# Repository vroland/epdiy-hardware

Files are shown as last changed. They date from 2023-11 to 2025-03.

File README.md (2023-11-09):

# EPDiy Hardware 

Design files for [EPDiy](https://github.com/vroland/epdiy) controllers, controller variants, display adaptors, and other related hardware.  
See [vroland.github.io/epdiy-hardware/](https://vroland.github.io/epdiy-hardware/) for available hardware.

## What is EPDiy?

Please refer to the [main project repository](https://github.com/vroland/epdiy) for more information.

## Cloning

Make sure to clone recursively, to get hardware library submodules:
```
git clone git@github.com:vroland/epdiy-hardware.git --recursive
# or with http
git clone https://github.com/vroland/epdiy-hardware.git --recursive
```

## Contributing Hardware

Contributions in the form of adapter boards, utilities or epdiy variants are always welcome!
Please submit a PR and make sure your KiCAD project is in the right format, so our automation can build 
the manufacturing files and overview page:

* For every board, the KiCAD project should be given a unique name, and have the same name as the containing folder. 
  Example: `epdiy-v7/epdiy-v7.{kicad_pro,kicad_pcb,kicad_sch}`. 
  An existing KiCAD project can be renamed by selecting `File -> Save As` in the main KiCAD window and saving it to a folder with the new name.
* Unless you *explicitly* specify otherwise, your contribution will be licensed under the Creative Commons Attribution-ShareAlike 4.0 International License.
  Feel free to mention in the README in your project folder how you want to be attributed.
  Please indicate in the PR if you intend to use a different license.
* Each board needs a README.md in it's project folder, which will also appear as description in the presentation page.
  Refer to `epdiy-v7/README.md` for an example.
* If it's a helper or an adapter board, place it in the appropriate `helpers` or `adapters` folder.
* Delete the manufacturing files and keep only the sources.
  Since we generate those automatically, having potentially outdated ones in the repo will be confusing. 
* Add your board to the `BOARDS` list in the root `Makefile`.
  This enables the continuous integration to build the manufacturing files for your board.

## Available Hardware

The full list of available hardware is available at [vroland.github.io/epdiy-hardware/](https://vroland.github.io/epdiy-hardware/).
For each board, we provide:

- Gerber files
- Bill of Materials (BoM)
- Pick & Place Positioning file
- PDF Schematic
- 3D model of the board for use in CAD

## Licensing

Unless otherwise specified, the hardware sources provided are licensed under the terms of the Creative Commons Attribution-ShareAlike 4.0 International License.
<a rel="license" href="https://creativecommons.org/licenses/by-sa/4.0/">Creative Commons Attribution-ShareAlike 4.0 International License </a>

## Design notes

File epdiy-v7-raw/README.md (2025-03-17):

### Epdiy V7 raw

This V7 controller iteration is based on the ESP32S3 for 8 bit panels. Highlights of the new board include:

- Support for 8-bit displays ED052TC* and 6 inches 'Kindle like' 34 pin panels
- No IO expander since we have enough pins. Plus MicroSD support to load images offline
- MPU6500 accelerometer so it can auto-detect rotation
- An optional ultra low consumption RV3032 RTC, LiPo charging

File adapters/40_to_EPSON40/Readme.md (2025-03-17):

### 40 pin to EPSON controller

This is an adapter that is meant to connect v7 40 pin FPC with a forward FPC cable to the 40 pin of an Epson S1D13524  controller.
Attention: This was done in a very experimental way and tested only once. Please review it to fit your specific circuit before doing any fabrication attempt!

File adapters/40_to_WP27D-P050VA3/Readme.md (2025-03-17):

### 40 pin to ED052TC* connector

This is a very simple adapter in case you want to test the 5.2 inch displays. Just use a 40 pin forward cable and respect the 1 - 50 indicators in the Silk to match the target display pins that are printed. This is a rule that should be followed before plugging any display to a controller

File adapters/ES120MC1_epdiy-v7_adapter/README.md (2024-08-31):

You'll need to remove the connector that come with the screen and solder a 50p uplink on top of it, and a 50p downlink and a 40p downlink on the board


You need to replace the R24 resistor on the board with 37K to get 28V屏幕截图 2024-04-23 065641

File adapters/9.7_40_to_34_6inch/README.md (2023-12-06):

## What it is

This PCB is an adapter from 40 pins (16 bit output) to 33 pins (6" output, leaving 8 GPIOs free)

It can come handy if you design a PCB that has no 33 pin connector. Or also to connect two 6" epaper, that will work showing exactly the same content, to any of the controlling boards.

Design: Martin Fasani  based on @vroland work.

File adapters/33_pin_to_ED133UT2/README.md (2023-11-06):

### Adapter from 33 pin 9.7" to ED133UT2

*Warning*: The ED133UT2 uses the same physical connector as the ED060SC4, but has a different pin configuration.
You can destroy your display if you connect it to the wrong connector!

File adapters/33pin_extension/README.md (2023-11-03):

### 33 Pin Extension Cable

Extension cable for 33 pin FPC connections.

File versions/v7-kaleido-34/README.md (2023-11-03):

### Epdiy V7

The V7 controller iteration is based on the ESP32S3. Highlights of the new board include:

- Support for high-resolution displays with 16 data lines
- Much faster updates thanks to the ESP32S3 SOC and the LCD peripheral
- An on-board RTC, LiPo charging

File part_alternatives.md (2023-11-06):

## Alternative Parts

Some components can be swapped for more cheaper or more available parts,
without impacting the functionality of the epdiy controlling board.
If you find other alternatives that may be useful to others, please submit a pull request!

| Part name | Replacement Name | Default LCSC ID | Replacement ID  | Comments |
| ---  | --- | --- | --- | --- |
| TPS651851RSLR  | TPS65185RSLR | C139292 | C702311 | Only if your panel size <= 9" |
| XF2M-3315-1A** | FH12-33S-0.5SH(55) | C231420 | C597986 | Omron connector is better quality than Hirose replacement |
| MBR0540T1G | B5819W SL | C8598 | C21353 | Much cheaper diode when ordering from LCSC |

** IMPORTANT: XF2M-3315-1A replacement C597986 uses a slightly different footprint. It has to be updated in KiCad PCB before sending fabrication files to production.

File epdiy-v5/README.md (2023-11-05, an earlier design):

### EPDiy V5

Older version of epdiy with power delivery based on the LT1945 IC. 
If the parts for newer revisions are available, it is highly recommended to use the newer revisions,
even if that means using adapter boards for dropped connectors.

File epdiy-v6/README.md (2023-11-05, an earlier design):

### Epdiy V6

Uses the TPS65185 IC for power delivery instead of the previous design and drops the ED060SC7 connector,
but adds additional available GPIOs though a GPIO expander.

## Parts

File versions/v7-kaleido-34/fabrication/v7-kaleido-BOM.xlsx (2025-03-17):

Designator | Footprint | Comment | JLCPCB Part #
R15,R1,R11,R10,R4,R6,R14,R16,R33,R32,R12 | R_0603_1608Metric | 10k | C25804
Q3,Q4 | SOT-23 | MMBT3904 | C20526
C3,C19,C9,C32,C12,C2,C16,C43,C45 | C_0805_2012Metric | 10uF | C15850
C22,C23,C30,C29,C15,C40,C42,C39 | C_0805_2012Metric | 100nF | C49678
D9 | LED_0805_2012Metric | LED RED | C84256
R3,R8 | R_0603_1608Metric | 1k | C21190
D8 | LED_0805_2012Metric | LED GREEN | C2297
C18,C13,C14 | C_0805_2012Metric | 1uF | C28323
C11,C5,C31,C8,C24,C1,C7,C4,C28,C26 | C_0805_2012Metric | 4.7uF | C1779
C34,C36 | C_1206_3216Metric | 1uF/50V | C1848
C35,C37,C38,C46,C44 | C_0805_2012Metric | 1uF/25V | C28323
R5 | R_0603_1608Metric | 0 | C21189
R18 | R_0603_1608Metric | 43k | C23172
R26,R27,R28,R29 | R_0603_1608Metric | 47k | C25819
TH1 | R_0603_1608Metric | 10k/3380K | C76589
U2 | TSSOP-24_4.4x7.8mm_P0.65mm | PCA9535PW | C255606
C17 | CP_EIA-3528-15_AVX-H | 100uF | C16133
R19,R23 | R_0603_1608Metric | 1M | C22935
L2 | L_Taiyo-Yuden_NR-40xx_HandSoldering | 2.2uH | C92959
L1 | L_Taiyo-Yuden_NR-50xx_HandSoldering | 4.7uH | C222947
R24 | R_0603_1608Metric | 47.5k | C25819
R20 | R_0603_1608Metric | 52.3k | C23196
U3 | TPS651851RSLR | TPS651851RSLR | C139292
C6,C10 | C_0805_2012Metric | 22uF | C45783
D6,D5,D3,D2,D4,D1,D12,D11,D7 | D_SOD-123 | MBR0540 | C21353
C27,C33 | C_0805_2012Metric | 2.2uF | C49217
C20,C25 | C_0805_2012Metric | 10nF | C1710
R30,R31 | R_0603_1608Metric | 100k | C25803
R22 | R_0603_1608Metric | 150k | C22807
R21 | R_0603_1608Metric | 680k | C25822
U11 | TP4056_SOP-8-PP | TP4056 | C16581
D10 | D_SOD-123 | 1N5817 | C8598
R9 | R_0603_1608Metric | 6.8k | C23212
J10 | AXT310124 | AXT-310124
U5 | SOT-23-3 | XC6206PxxxMR | C5446
U4 | SOT-666 | USBLC6-2P6 | C2827693
L4,L3 | SWPA5040S282MT | 22uH | C68434
U10 | X05A20H34G | ED060XC5 | C528053
Q1 | SOT-23 | AO3401A | C15127
R17,R13 | R_0603_1608Metric | 25Ω | C308324
C21,C41 | C_0805_2012Metric | 12pF | C1792
U6,U12 | SOT-23-6_RY3730_Led_PWM | RY3730
J4,J9 | CONN8_FH34SRJ_HIR | Conn_01x08_Pin | C88372
U7 | SOIC-8_3.9x4.9mm_P1.27mm | PCF8563T
R7,R2 | R_0603_1608Metric | 5.1k | C23186
R34,R25 | R_0603_1608Metric | 33k | C4216
J6 | FH34SRJ6S05SH99_Mirrored | FH34SRJ-6S-0.5SH_99_ | C224194
U1 | TSOT-23-5 | RT9080-33GJ5 | C841192
J12 | QWIIC_SM04B-SRSS-TB_LFSN_ | SM04B-SRSS-TB_LF__SN_ | C160404
U8 | ESP32-S3-WROOM-1 | ESP32-S3-WROOM-1
RN1 | RESN_F392JTCE_UNR_SD-pullup | R_Pack04 | C425297
U9 | SOIC-16_3.9x9.9mm_P1.27mm | CH340C | C84681
J1 | USB_C_Receptacle_HRO_TYPE-C-31-M-12 | USB_C_Receptacle_USB2.0 | C165948
J11 | THD252811SDGF | THD2528-11SD-GF | C283232
Y1 | Crystal_SMD_3215-2Pin_3.2x1.5mm | 32.768K | C32346

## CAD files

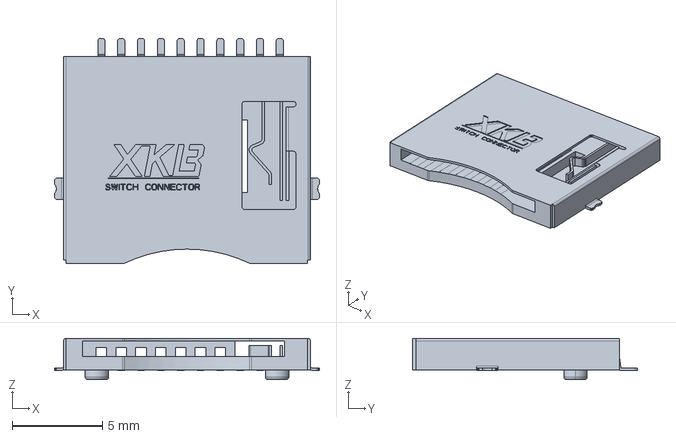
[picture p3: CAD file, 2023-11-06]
helpers/40_pins_PCB_tester/component/3d/XKTF-005-SD.stp
14.7 x 12.5 x 2.30 mm

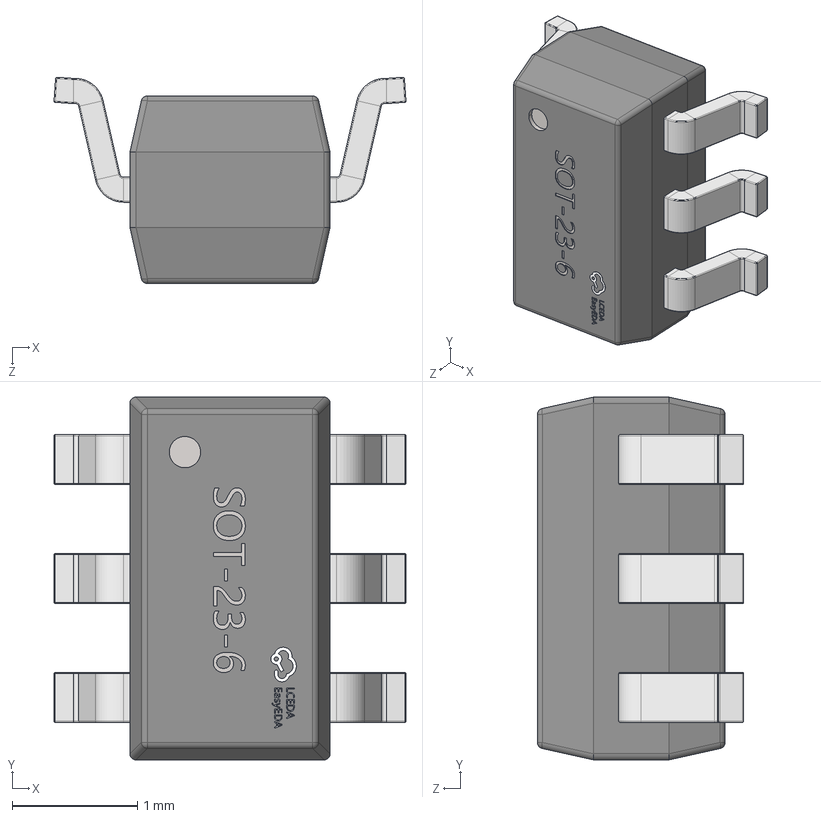
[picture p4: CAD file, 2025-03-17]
versions/v7-kaleido-34/3dmodels/SOT-23-6_RY3730_Led_PWM.step
2.81 x 2.90 x 1.65 mm

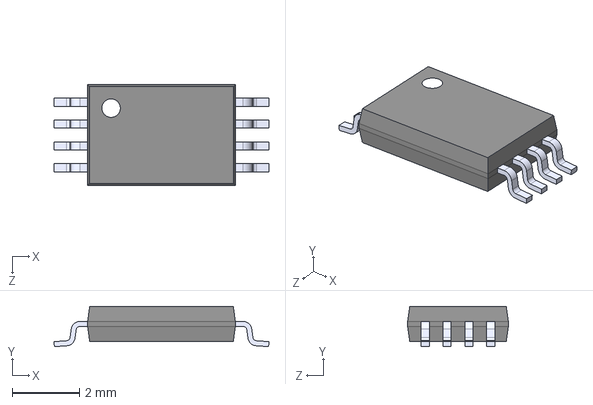
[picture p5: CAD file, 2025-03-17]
epdiy-v7-raw/components/3d/tps2113apwr.step
6.40 x 1.20 x 3.00 mm

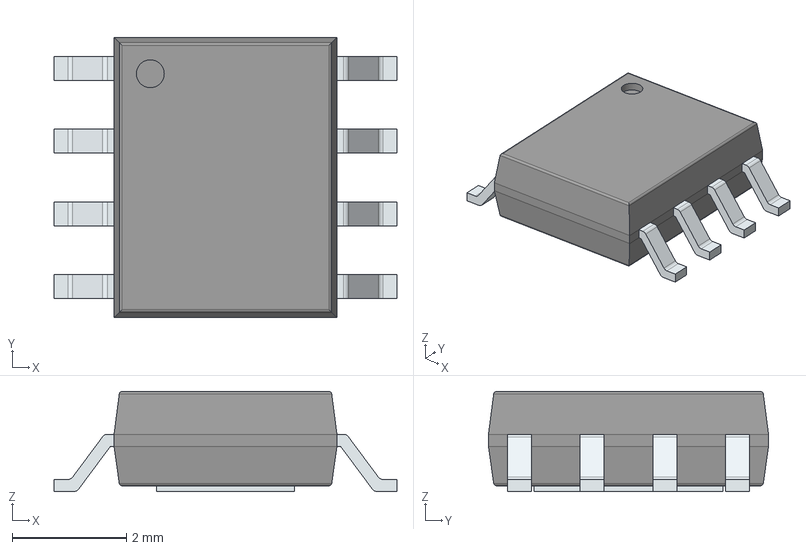
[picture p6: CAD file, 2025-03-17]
versions/v7-kaleido-34/3dmodels/TP4056-42-ESOP8.step
6.00 x 4.90 x 1.75 mm
PinsArrayLR
ThermalPad

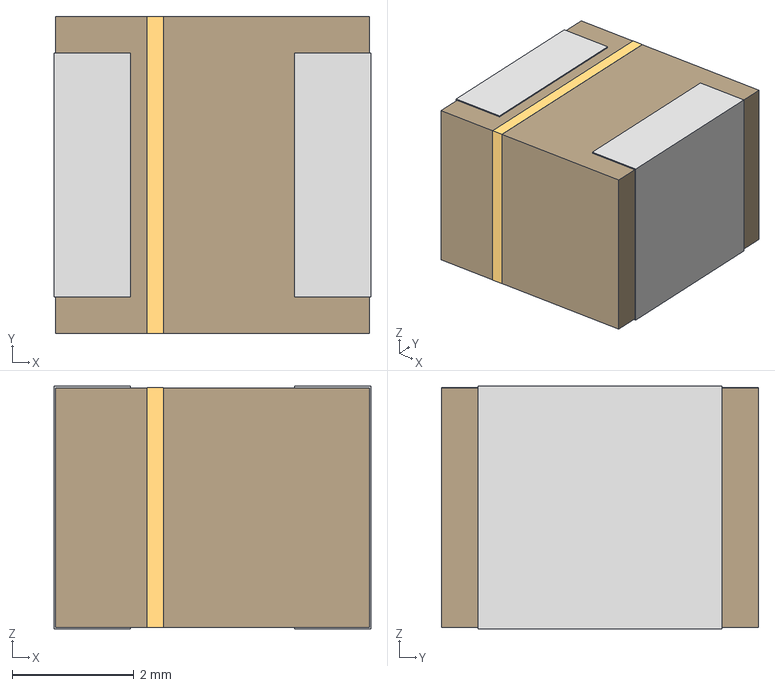
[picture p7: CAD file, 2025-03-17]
epdiy-v7-raw/components/3d/IND_0S282MT_SNL.step
5.21 x 5.21 x 3.99 mm

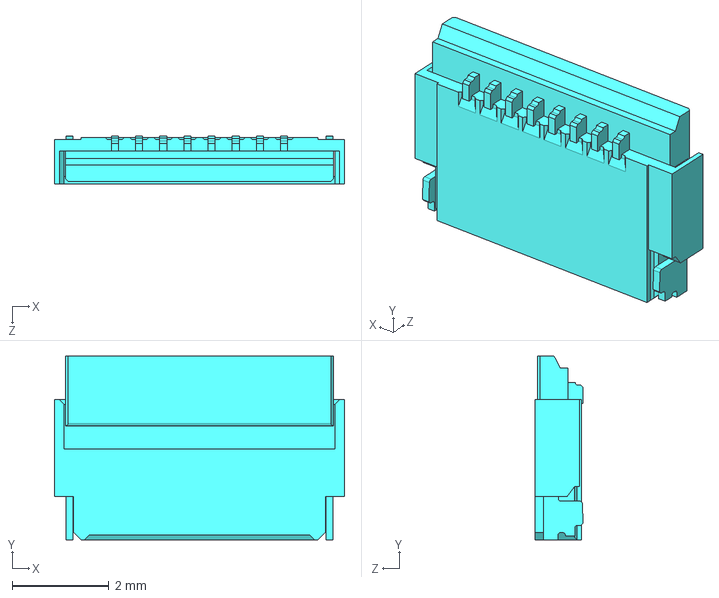
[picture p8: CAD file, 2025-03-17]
versions/v7-kaleido-34/3dmodels/FH34SRJ-8S-0.5SH_50.step
6.00 x 3.80 x 1.00 mm

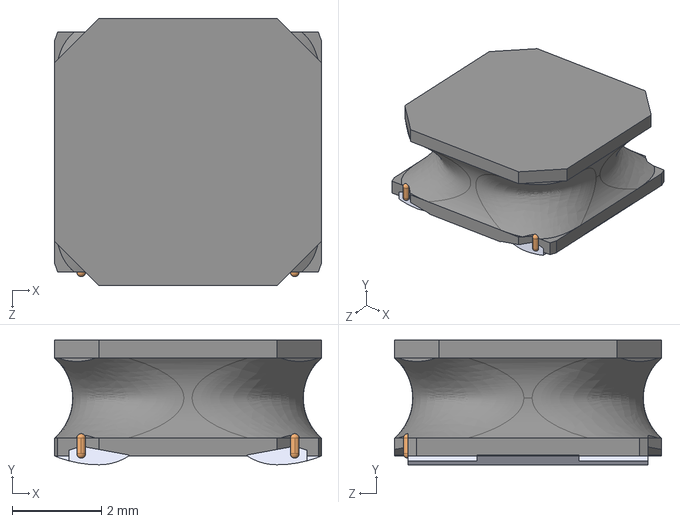
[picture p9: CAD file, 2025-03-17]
epdiy-v7-raw/components/3d/L-40xx.STEP
6.00 x 2.80 x 6.00 mm

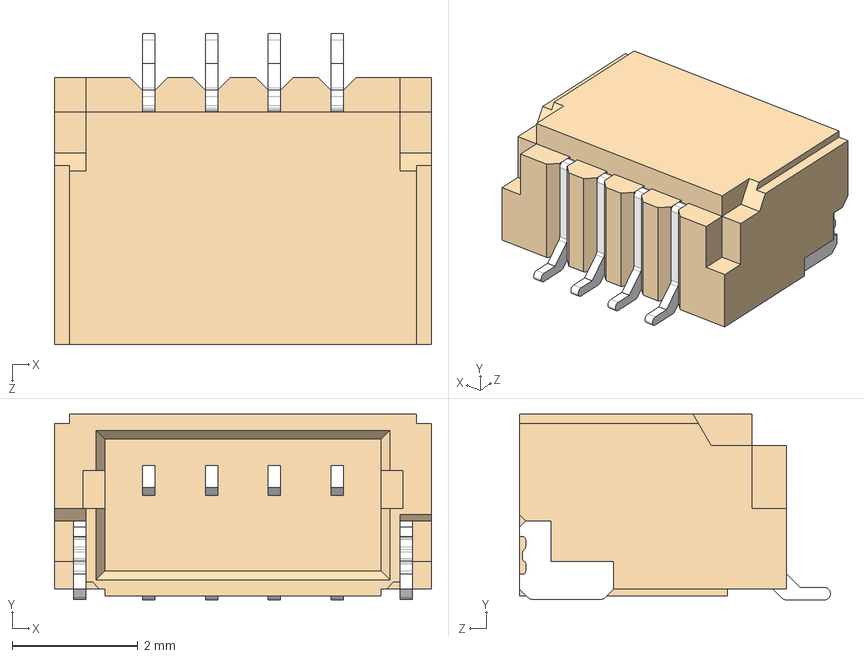
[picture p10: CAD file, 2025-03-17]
versions/v7-kaleido-34/3dmodels/QWIIC_SM04B-SRSS-TB_LF__SN_.stp
6.00 x 2.96 x 4.95 mm

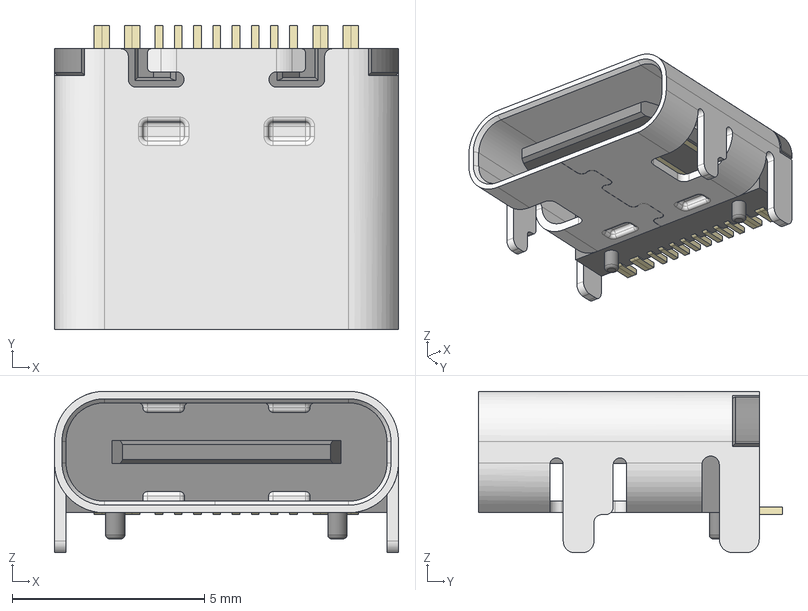
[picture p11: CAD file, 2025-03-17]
epdiy-v7-raw/components/3d/USB_TYPE-C-31-M-12.step
8.95 x 7.90 x 4.20 mm

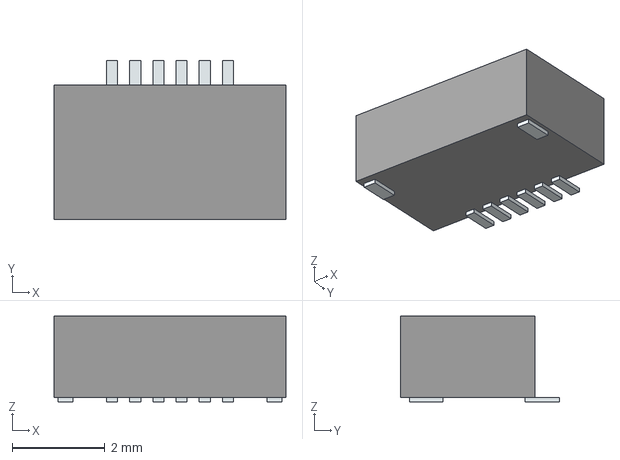
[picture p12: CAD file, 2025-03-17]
versions/v7-kaleido-34/3dmodels/FH34SRJ-6S-0.5SH_99.step
5.00 x 3.42 x 1.85 mm
Pins

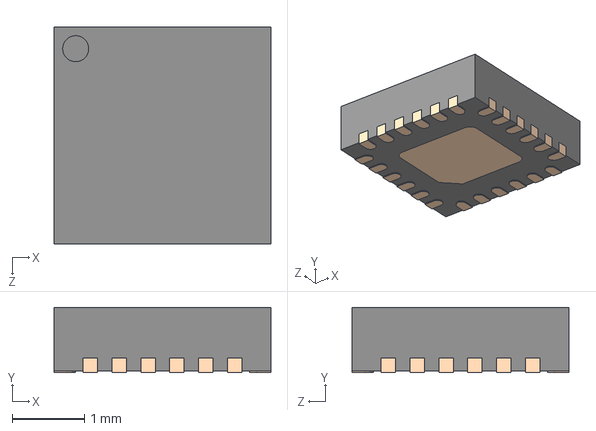
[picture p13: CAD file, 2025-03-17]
epdiy-v7-raw/components/3d/MPU-6500.stp
3.00 x 0.9 x 3.00 mm

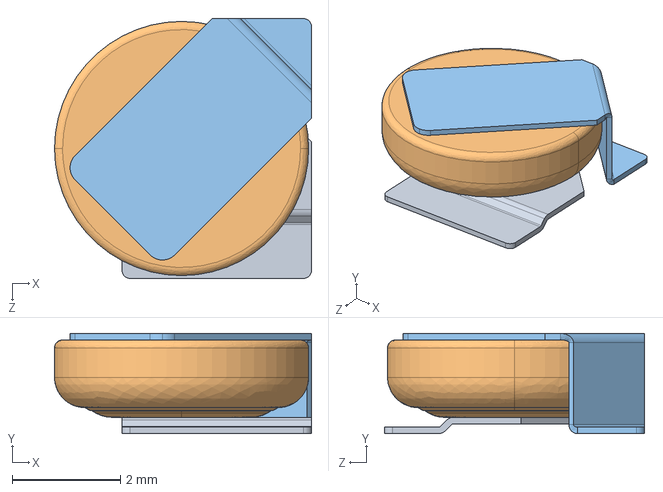
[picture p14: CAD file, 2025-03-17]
epdiy-v7-raw/components/3d/SuperCAP_XH414HG-IV01E.stp
4.75 x 1.85 x 4.80 mm

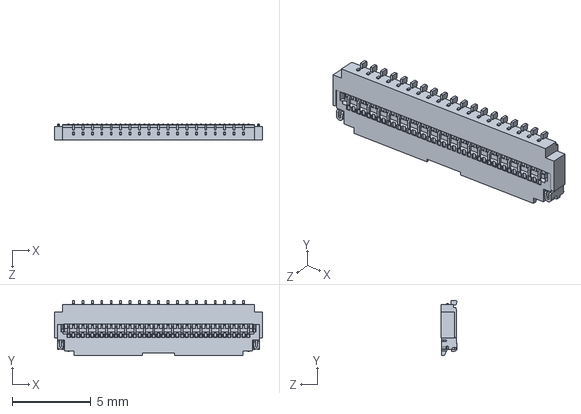
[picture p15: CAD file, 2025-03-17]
epdiy-v7-raw/components/3d/HRS-FH26W-39S.STEP
13.2 x 3.50 x 1.00 mm

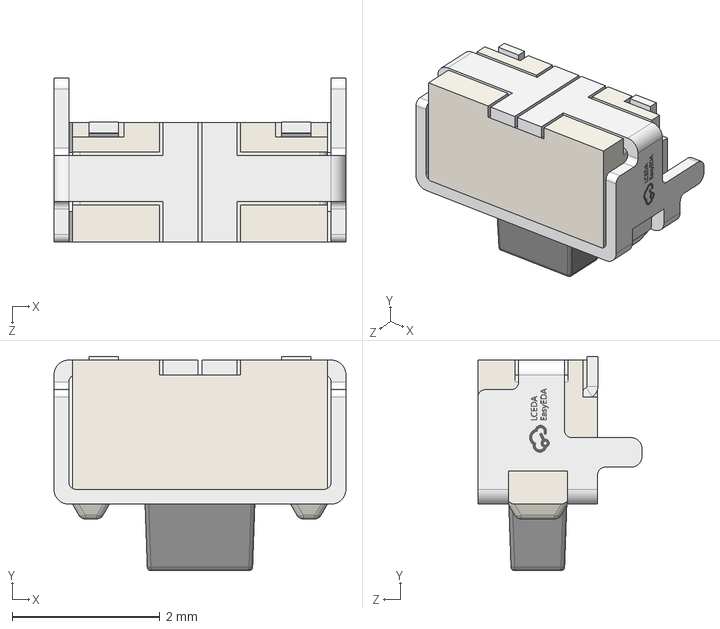
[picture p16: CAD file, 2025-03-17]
epdiy-v7-raw/components/3d/KEY-SMD_K2_L4.0-W2.9-H1.6-P3.75.step
3.95 x 2.90 x 2.22 mm

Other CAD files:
epdiy-v7-raw/components/3d/THD2528-11SD-GF_microSD.step
epdiy-v7-raw/components/3d/RV-3032-C7.stp
epdiy-v7-raw/components/3d/xf2m-3315-1a.step
epdiy-v7-raw/components/3d/S2B-PH-SM4-TB_LF_BatteryJACK.stp
epdiy-v7-raw/components/3d/C2916320_SMTSO2015CTJ.stp
epdiy-v7-raw/components/3d/FH12-33S-0.5SH.step
epdiy-v7-raw/components/3d/TPS651851RSLR.step
epdiy-v7-raw/components/3d/Tactal Switch - SMD (5mmx 5mmx1.5mm).stp
epdiy-v7-raw/components/3d/X05A20H34G_EPD_connector.step

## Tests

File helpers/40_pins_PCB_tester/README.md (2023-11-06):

## What it is

This PCB is just a tester that comes handy if you want to check that all GPIOs, the 16 data lines plus other 7 signals, are correctly soldered in your PCB.
After this comes just need to make a easy program, put all GPIOs in an array, and sequence them HIGH/ LOW.

NOTE: This needs a 40 pin Reversed cable in order to be connected to epdiy v7

Additionally in the 2nd panel has a small MicroSD raw adapter with the pin-out since it's really cheap to have one and at the same time of doing this tester, I wanted to research a way to add MicroSD support to an epdiy PCB.

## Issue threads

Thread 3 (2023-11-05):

list of art alternatives

vroland, 2023-11-05:
As requested in https://github.com/vroland/epdiy/issues/260, it would be useful to have a comprehensive list of part alternatives that are cheaper / more available, like TPS651851/TPS65185, schottky diodes, FPC connectors, etc.

martinberlin, 2023-11-05:
I can contribute with one:

XF2M-3315-1A | Omron 9.7" 33 pin connector | C231420  is currently 3.2 $ (Last time wanted to pre-order 20)
This could be replaced for cheaper C597986, Hirose connector which is 0.50 usd when buying 30 and up to 70 cents when buying less quantity.

For me the only important point of FPC connectors apart that they must have the same 0.5 mm pitch is that they have only bottom connection. Double-sided are dangerous since connecting displays in the opposite way you can send voltages to pins that only are supposed to get 3.3V and damage your PCB (Or the display)

martinberlin, 2023-11-06:
Proposed format:
https://github.com/vroland/epdiy-hardware/wiki/Alternative-components
Feel free to expand and add a new column to the table if needed.

vroland, 2023-11-06:
Thanks!
I moved this to a markdown file to make contributing easier, and it's now also built into the presentation page :)

Closed 2023-11-06.

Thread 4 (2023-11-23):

About V7 new board

dengfengdz, 2023-11-23:
Hi ,I make some new V7 board，But there are some problems I can't understand，I use the board to display ES108FC1,When I don't plug in the screen，Serial port logs are normal，The voltage at the test point is also normal，When the screen is connected, the voltage will be lowered from +-22v to around +-15.8v.I checked the specs on the chip,The  TPS65185 Maximum support 120mA. Bom message is use the TPS65185 ,But Schematic diagram use TPS651851,The  TPS65185 Maximum support 200mA. So I wonder if this is the reason for my problems.

martinberlin, 2023-11-23:
Hi @dengfengdz I'm transferring this issue to https://github.com/vroland/epdiy-hardware
Since the Hardware is now over there it can get the right attention in that repository and we keep this one from now on for the component part.

dengfengdz, 2023-11-24:
I'd like to try but I only have 10.8 "and 13.3" ink screens，I made five V7 boards，only one piece can be displayed properly.This makes me very confused.If it is because the TPS65185 drive capacity is not enough,there's also a drive board that works.

dengfengdz, 2023-11-24:
I'd like to try but I only have 10.8 "and 13.3" ink screens，I made five V7 boards，only one piece can be displayed properly.This makes me very confused.If it is because the TPS65185 drive capacity is not enough,there's also a drive board that works.
Today, I will buy TPS651851 to try whether it is caused by the problem I said.And I can't find anything else wrong with it.When I'm not connected to the screen,I measured the output voltage on this chip and it's all normal

dengfengdz, 2023-11-24:
Hi@martinberlin  I have tried to replace TPS651851,The phenomenon is the same as before.I don't have any other ideas right now,
The program will stay stuck in an endless loop,And just like before, when I put my finger on the red area, the program worked
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
Does this mean that there is something wrong with TPS65185？

martinberlin, 2023-11-24:
@vroland do you have any idea why it can be that TPS65185 does not trigger the PWRGOOD line?  But it seems to work if he places his finger at the left side marked with the red area.
I never experienced something like this so far.

vroland, 2023-12-06:
Hm, did you use any alternative parts @dengfengdz for coils, etc? It seems to me like either the TPS is not soldered properly or something else is preventing the boost circuitry from starting up properly. Do you have access to an oscilloscope to measure the voltages in the area you're touching?

Closed 2023-12-07.

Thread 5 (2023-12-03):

CAUTION: 33 pin to 34 pin (6 inch) adapter is not working as expected

martinberlin, 2023-12-03:
This PCB is an adapter from **9.7" (33 pins)** and 40 pins (16 bit output) to 33 pins (6" output)

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

The 40 to 34 pin adapter works correctly. The one marked does not just leaving a black top right part in the display. Does not seem to heat-up or do any damage but please do not use.

@vroland I will either find out what it is in the next days or submit a PR just taking out the adapter and leaving only the one that works.
I've went through Schematic comparing latest v7 33 & 34 pins and looks just fine. So there must be something in the board itself that is not. Very strange. Please don't use until we discover what is going on!

Closed 2023-12-06.

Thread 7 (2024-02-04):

v7 board does not specify display type on the silkscreen

hramrach, 2024-02-04:
Up to v6 board the silksceen would have exact display type, while v7 only has the pin count. As the ED133UT2 adapter attests pin count is not sufficient to determine the screen type.

As such going from screen type to pin count looks like a regression to me.

martinberlin, 2024-02-04:
Just my opinion: I disagree.
Epdiy really drives many different Eink displays that are specified in the table on the repository index. Having the pin count is the right thing to do since you cannot just list all the different models in the silkscreen.
All have the same driving principle so all that matters is the pin count and that connector matches, all the rest should be solved in the firmware

hramrach, 2024-02-05:
> Epdiy really drives many different Eink displays that are specified in the table on the repository index. Having the pin count is the right thing to do since you cannot just list all the different models in the silkscreen. All have the same driving principle so all that matters is the pin count and that connector matches, all the rest should be solved in the firmware

And that's exactly the problem, this is not true. ED060SC4 and ED133UT2 use exactly the same connector, and same driving principle but completely different pinout. The pinout of the 33pin connector is compatible with ED060SC4 but if you connect ED133UT2 to it without the correct adapter it will not work and likely burn down. The pinout of the 33pin connector is for ED060SC4 and isplays with compatible pinout, and not for ED133UT2. This was clear with the previous revision looking at the silkscreen, with the latest revision this information is lost.

martinberlin, 2024-02-05:
> ED060SC4 and ED133UT2 use exactly the same connector

sure in this I agree. But first things first: [Official v7 PCB](https://github.com/vroland/epdiy/blob/main/doc/source/img/hardware_page.png) does NOT have a 39 pin connector so I don’t really see why it should mention either of those models

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

I did make my own v7 for and added a 13.3” connector but signaled what display its for in the Silkscreen
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

martinberlin, 2024-02-05:
I would simply add the size like:
33 pins 9.7”
34 pins 6” and if someone needs to adapt it just add the particular display name
40 is 16 bits and there are many different models that use it from Eink to Wuxi Weifeng DES and maybe more

Ideally the concept of adding 3 different FPC connectors is that mostly you leave just the one that you will use for your project. Having 3 is to facilitate the first time testers to get on board without complications.
I would personally avoid as much as possible to use adapters.

hramrach, 2024-02-05:
> 33 pins 9.7”
At which point you are back to the specific display model, except in a vague, roundabout way.

martinberlin, 2024-03-15:
This board is open source and actually everyone can edit it before sending it to fabrication and personalize it to their needs. I do not see any functional issue and for me the v7 has the right silkscreen.
I do not see any point to name it differently since 9.7 could be ED097TC2 for some users, or ED097OC1 for others, or any other 33 pin displays with same pin-out.

Closed 2024-03-15.

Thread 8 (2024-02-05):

ED133UT2 to ED060SC4 adapter described as 33pin while display datasheet for both displays says they are 39pin

hramrach, 2024-02-05:

martinberlin, 2024-02-05:
I don’t really get this one.

> ED133UT2 to ED060SC4 adapter

Where is that adapter? Can you please be more specific and post a link to it.

The only one I see in new hardware repo is: _**Adapter from 33 pin 9.7" to ED133UT2**_

hramrach, 2024-02-05:
https://github.com/vroland/epdiy-hardware/tree/main/adapters/33_pin_to_ED133UT2

https://github.com/vroland/epdiy-hardware/blob/main/adapters/33_pin_to_ED133UT2/README.md
>Adapter from 33 pin 9.7" to ED133UT2
>Warning: The ED133UT2 uses the same physical connector as the ED060SC4, but has a different pin configuration. You can destroy your display if you connect it to the wrong connector!

These are 39pin displays according to specification, not 33pin.

martinberlin, 2024-02-06:
> These are 39pin displays according to specification, not 33pin.

sure but is clear that is an adapter hence it says:
33 pin to other display

That means that you need to connect it to 33 pins and then it gets out with 39 pin. Again I don’t see the issue.
It should be just properly labeled: Input 33, output 39

hramrach, 2024-02-06:
Oh, so you are supposed to use a 39pin connector on the board (if you have one, which is not longer the case with v7) for ED060SC4 and the 33pin to 39pin adapter for ED133UT2.

That's completely confusing.

Maybe switching the display type 'specification' to the pin count was a really bad idea.

martinberlin, 2024-02-06:
No you use a 33 pin from board to adapter and then directly connect the display.
Again there is no 39 pin connector in v7.

Michal if you dislike the board please be my guest and design your own. You already forked this repository so just update it as it pleases you before sending it to fabrication. That’s the greatest thing of open source.
You don’t need to complain about every little thing you dislike. Just change it

hramrach, 2024-02-06:
Yes, 'just fork'.

The problem is that when the description is bad you have to go through several stages of confusion before doing any actual work on the project. That's a bug that is worth fixing upstream.

martinberlin, 2024-02-06:
If you tell me your email I will add you to the epdiy channel in Slack. Then in case of any doubt you can talk there with people that already went through testing this or that display and might help you to get started right

martinberlin, 2024-04-15:
You can also use this new channel to discuss about adapters and get help
https://github.com/vroland/epdiy/discussions

Closed 2024-02-06.

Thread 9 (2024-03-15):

ES120MC1 ADAPTER

3058132083, 2024-03-15:
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
I need some design guidance on converting 40pin to 50pin EPD, and it seems that there are some pins that don't have the right definitions.
[ES120MC1_VD1400-MOA_Formal spec_ver 1.0.pdf](https://github.com/vroland/epdiy-hardware/files/14611943/ES120MC1_VD1400-MOA_Formal.spec_ver.1.0.pdf)
[https://www.waveshare.net/w/upload/b/b4/7.8inch_e-Paper_Specification.pdf](url)

martinberlin, 2024-03-15:
>  it seems that there are some pins that don't have the right definitions.

Please clarify what are the pins that you are missing in clear text. I see only that :
SPV (start pulse vertical, active low)   is missing on the right, maybe they use another name?
Any other?  But SPV is the right name for this pin you can also check that this website http://essentialscrap.com/eink/waveforms.html

3058132083, 2024-03-15:
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
I didn't find the definition of SPV in the ES120MC1 datasheet, and I would like to know how to convert 36-50 pins

martinberlin, 2024-03-16:
Assigning this to @vroland
I’m not sure if this will work with a simple pin adapter. There 2 STV inputs please post a link to the data sheet or send it to me by email to martin@cale.es

3058132083, 2024-03-17:
[ES120MC1_VD1400-MOA_Formal.spec_ver.1.0.pdf](https://github.com/vroland/epdiy-hardware/files/14626204/ES120MC1_VD1400-MOA_Formal.spec_ver.1.0.pdf)

3058132083, 2024-03-19:
By the way, I didn't find a way to buy the corresponding model of connector, so I designed an FPC and removed the original connector to solder directly.
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
Once I figured out the correct pin definition, I was able to prototype the FPC and verify the feasibility.

3058132083, 2024-04-22:
Good news,the adapter works well,but the display just can't work well.

`ESP-ROM:esp32s3-20210327
Build:Mar 27 2021
rst:0xc (RTC_SW_CPU_RST),boot:0x8 (SPI_FAST_FLASH_BOOT)
Saved PC:0x403758cc
0x403758cc: esp_restart_noos at C:/Users/Administrator/esp/v4.4.7/esp-idf/components/esp_system/port/soc/esp32s3/system_internal.c:151 (discriminator 1)

SPIWP:0xee
mode:DIO, clock div:1
load:0x3fce3808,len:0x148c
load:0x403c9700,len:0xe60
load:0x403cc700,len:0x3060
entry 0x403c9970
I (29) boot: ESP-IDF v4.4.7 2nd stage bootloader
I (29) boot: compile time 22:54:23
I (29) boot: Multicore bootloader
I (31) boot: chip revision: v0.2
I (35) qio_mode: Enabling default flash chip QIO
I (40) boot.esp32s3: Boot SPI Speed : 80MHz
I (45) boot.esp32s3: SPI Mode       : QIO
I (50) boot.esp32s3: SPI Flash Size : 16MB
I (54) boot: Enabling RNG early entropy source...
I (60) boot: Partition Table:
I (63) boot: ## Label            Usage          Type ST Offset   Length
I (71) boot:  0 nvs              WiFi data        01 02 00009000 00006000
I (78) boot:  1 phy_init         RF data          01 01 0000f000 00001000
I (86) boot:  2 factory          factory app      00 00 00010000 00177000
I (93) boot: End of partition table
I (97) esp_image: segment 0: paddr=00010020 vaddr=3c020020 size=d9d90h (892304) map
I (241) esp_image: segment 1: paddr=000e9db8 vaddr=3fc95680 size=02424h (  9252) load
I (243) esp_image: segment 2: paddr=000ec1e4 vaddr=40374000 size=03e34h ( 15924) load
I (250) esp_image: segment 3: paddr=000f0020 vaddr=42000020 size=1cdc4h (118212) map
I (273) esp_image: segment 4: paddr=0010cdec vaddr=40377e34 size=0d848h ( 55368) load
I (284) esp_image: segment 5: paddr=0011a63c vaddr=600fe000 size=0002ch (    44) load
I (291) boot: Loaded app from partition at offset 0x10000
I (291) boot: Disabling RNG early entropy source...
I (304) cpu_start: Multicore app
I (304) opi psram: vendor id : 0x0d (AP)
I (305) opi psram: dev id    : 0x02 (generation 3)
I (307) opi psram: density   : 0x03 (64 Mbit)
I (312) opi psram: good-die  : 0x01 (Pass)
I (317) opi psram: Latency   : 0x01 (Fixed)
I (321) opi psram: VCC       : 0x01 (3V)
I (326) opi psram: SRF       : 0x01 (Fast Refresh)
I (332) opi psram: BurstType : 0x01 (Hybrid Wrap)
I (337) opi psram: BurstLen  : 0x01 (32 Byte)
I (342) opi psram: Readlatency  : 0x02 (10 cycles@Fixed)
I (348) opi psram: DriveStrength: 0x00 (1/1)
I (354) MSPI Timing: PSRAM timing tuning index: 5
I (358) spiram: Found 64MBit SPI RAM device
I (363) spiram: SPI RAM mode: sram 80m
I (368) spiram: PSRAM initialized, cache is in normal (1-core) mode.
I (375) cpu_start: Pro cpu up.
I (378) cpu_start: Starting app cpu, entry point is 0x40375198
0x40375198: call_start_cpu1 at C:/Users/Administrator/esp/v4.4.7/esp-idf/components/esp_system/port/cpu_start.c:151

I (363) cpu_start: App cpu up.
I (680) spiram: SPI SRAM memory test OK
I (689) cpu_start: Pro cpu start user code
I (689) cpu_start: cpu freq: 240000000
I (689) cpu_start: Application information:
I (691) cpu_start: Project name:     firmware
I (697) cpu_start: App version:      2.0.0-11-g2803a55-dirty
I (703) cpu_start: Compile time:     Apr 18 2024 22:54:04
I (709) cpu_start: ELF file SHA256:  e32b7a19b742f016...
I (715) cpu_start: ESP-IDF:          v4.4.7
I (720) cpu_start: Min chip rev:     v0.0
I (724) cpu_start: Max chip rev:     v0.99
I (729) cpu_start: Chip rev:         v0.2
I (734) heap_init: Initializing. RAM available for dynamic allocation:
I (741) heap_init: At 3FC98688 len 00051088 (324 KiB): D/IRAM
I (748) heap_init: At 3FCE9710 len 00005724 (21 KiB): STACK/DIRAM
I (754) heap_init: At 3FCF0000 len 00008000 (32 KiB): DRAM
I (761) heap_init: At 600FE02C len 00001FD4 (7 KiB): RTCRAM
I (767) spiram: Adding pool of 8192K of external SPI memory to heap allocator
I (775) spi_flash: detected chip: generic
I (779) spi_flash: flash io: qio
I (784) sleep: Configure to isolate all GPIO pins in sleep state
I (790) sleep: Enable automatic switching of GPIO sleep configuration
I (797) cpu_start: Starting scheduler on PRO CPU.
I (0) cpu_start: Starting scheduler on APP CPU.
I (818) spiram: Reserving pool of 32K of internal memory for DMA/internal allocations
I (818) gpio: GPIO[45]| InputEn: 0| OutputEn: 1| OpenDrain: 0| Pullup: 0| Pulldown: 0| Intr:0
I (828) epdiy: using resolution 320x1600
I (838) epdiy: num dma nodes: 1
I (838) epdiy: size: 2568 max: 4095
I (848) epdiy: pclk freq: 16000000 Hz
I (848) epdiy: line width: 21us, 336 cylces
I (848) epdiy: LCD init done.
E (858) epd: lut size: 65536
Dimensions after rotation, width: 2560 height: 1600
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
3058132083, 2024-04-22:
Besides,there are strange lines on the screen.
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

3058132083, 2024-04-22:
The white parts looks good
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

3058132083, 2024-04-22:
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
I set the bus_speed to 12 and it now shows the zebra and v2 board fine, but the picture behind still doesn't show up properly

martinberlin, 2024-04-22:
This line looks to me if there is one of the data GPiOs that is either Grounded or not connected to the MCU. Please check connectivity from display to each of the MCU IOs. It might be in rare occasions that also one GPIO is dead. Happened to me once and got me crazy until I found it

vroland, 2024-04-22:
Hey, nice work on the adapter overall, looks like an iteresting display! You can try the vector-extensions branch of epdiy and set the PSRAM speed to 120MHz, then try to increase the speed. Maybe you get some faster refresh out of it.

Regarding the stripes: As @martinberlin said it's likely a bad connection on one of the GPIOs (worst case it is dead). There are two bits per pixel, basically one line to make it lighter and one to make it darker. So it could be that the pattern for "whiter" works, but the one for "darker" doesn't or is unreliable.

And to attach the adapter you just soldered the FPC onto the display?

3058132083, 2024-04-22:
[>](https://github.com/vroland/epdiy-hardware/pull/13)

vroland, 2024-08-31:
Closing since #13 is merged.

Closed 2024-08-31.

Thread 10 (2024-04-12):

EPDiy V5 condenser C1 and C16's placement is wrong.

paruparu, 2024-04-12:
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

The board EPDiy V5 berber file or the silk screen print is wrong. (C1 and C16 condenser)
I can't figure out if the print is wrong or the placement of the condenser is wrong.

vroland, 2024-04-22:
Hi, indeed the labels for C1 / C16 where swapped. Should be fixed in main now.

paruparu, 2024-05-05:
I have found out that the silk print is wrong. C1 condenser goes on the upper part and C16 condenser goes on the lower part.

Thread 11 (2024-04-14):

Spare boards in the Uk

letshin, 2024-04-14:
Hi, does anyone have any spares they would be happy to post in the UK/EU?

martinberlin, 2024-04-15:
Hello Letshin,
Please use the discussion board here:
https://github.com/vroland/epdiy/discussions

This is the Issue board of hardware and not a proper channel to ask for help or boards.
You can also buy a board from me on Tindie next week when I add stock (but only v7 boards)

Closed 2024-04-15.

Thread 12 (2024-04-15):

Alternative to esp32-wroom

letshin, 2024-04-15:
HI, is there an alternative to the esp32-wroom please as JLCPCB says this is only doable on a standard order which adds to the cost of small batches. Is it possible to replace it with a esp-12f for example?

martinberlin, 2024-04-15:
That’s not a good idea you need to use the chip specified in the BOM.
Do not ask for that part assembled and just solder it yourself. It’s not such a hard work and we’ve all did it at some point even with basic soldiering tools.
Good luck!

Closed 2024-04-15.

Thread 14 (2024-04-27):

Missing parts in BOM

maximelouet, 2024-04-27:
Hi, and thanks a lot for providing all of this!!

I'm trying to get the board printed and assembled through JLCPCB but I get the following error when uploading the gerbers and BoM files:

```
The below parts won't be assembled due to data missing.
J2,J3,J5,J6,J7 designators don't exist in the BOM file.
```

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

Indeed, when checking in the BoM file, these 5 items are missing. These parts don't seem to be optional, so I don't really want to continue without them.

It seems they've been removed from the BoM in this commit: https://github.com/vroland/epdiy-hardware/commit/f67d0ec701ee9243f95e018740200eee1eb12c22, I don't know if it was intentional.

Thanks for your help!

martinberlin, 2024-04-28:
Hi Máxime,
J* symbols in KiCad refer to Jumpers or Sockets which are non parts usually. It could be that are in the POS file and that’s why this alert comes. Try opening with KiCad and check it out. Is a good idea to learn using it if you will send PCBs to fabrication

martinberlin, 2024-08-31:
Closed #16 since was a duplicate of this.
Will check tomorrow to mark this parts not to be exported in BOM /CPL

BackSlasher, 2024-08-31:
@martinberlin apologies if it's a stupid question - do you consider int a valid workaround to remove the J parts from the positioning file and submit to the assembling store?
Will I not be missing parts?

martinberlin, 2024-08-31:
Not really. You should install KiCad and check it out. It’s not essential but recommended if you send stuff to fabrication, then you can check everything, from schematic to PCB.
If you check schematic you will see also what are those parts. Usually J* are jumpers so this are not placeable components just drawn in the Gerbers files

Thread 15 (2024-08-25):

SMT component placed incorrectly（by using JLC）

lmx0125, 2024-08-25:
When placing SMT, the component is placed incorrectly.

martinberlin, 2024-08-25:
Moved to epdiy-hardware since the other main repository is only for the firmware.
@lmx0125 please describe in detail what went wrong I didn’t had this problem when producing the PCB using the provided files

martinberlin, 2024-12-08:
Closing this since there was no feedback in more than 3 months

Closed 2024-12-08.

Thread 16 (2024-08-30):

v7 on JLCPCB: "designators don't exist in the BOM file."

BackSlasher, 2024-08-30:
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

Trying to order a built v7.

I went to the [hardware page](https://vroland.github.io/epdiy-hardware/), then chose JLCPCB.

Uploaded `epdiy-v7-gerbers.zip`, then on the next stage `epdiy-v7_BoM.csv` and `epdiy-v7_pos_jlcpcb.csv`. Attached them here in case it helps.

[epdiy-v7-gerbers.zip](https://github.com/user-attachments/files/16819738/epdiy-v7-gerbers.zip)
[epdiy-v7_BoM.csv](https://github.com/user-attachments/files/16819739/epdiy-v7_BoM.csv)
[epdiy-v7_pos_jlcpcb.csv](https://github.com/user-attachments/files/16819740/epdiy-v7_pos_jlcpcb.csv)

The dialog complains about J2,J3,J5,J6,J7 existing in the placement file but not in the BoM file, and as far as I can see it's correct.
From the placement file:
```
"J2","EXTENSION_HEADER","PinHeader_1x13_P2.54mm_Vertical",31.875000,-11.300000,90.000000,top
"J3","USB_HDR","PinHeader_1x02_P2.54mm_Vertical",27.100000,-20.375000,180.000000,top
"J4","XF2M-3315-1A","CONN_ED097OC4",106.800000,-17.216750,0.000000,top
"J5","CONN_BAT","PinHeader_1x02_P2.54mm_Vertical",27.350000,-49.275000,0.000000,top
"J6","8BIT_HEADER","PinHeader_1x10_P2.54mm_Vertical",122.936000,-50.800000,180.000000,top
"J7","ESP_HDR","PinHeader_1x12_P2.54mm_Vertical",66.000000,-11.300000,90.000000,top
```
The BoM includes only J1,J4:
```
"USB_C_Receptacle_USB2.0","J1","Connector_USB:USB_C_Receptacle_HRO_TYPE-C-31-M-12","C165948"
"XF2M-3315-1A","J4","epaper-breakout:CONN_ED097OC4","C231420"
```
I couldn't find the missing pieces in the BoM by name, so they seem to me like they're indeed missing from the BoM.
Am I missing something?
Thank you for the help and for this project!

martinberlin, 2024-08-30:
@BackSlasher moving this to the right repository since the other one is only for the firmware. Will take a look this weekend to see what is missing there

martinberlin, 2024-08-31:
This was already reported on #14
It seems those J* parts are Jumpers that indeed do not represent a part in the BOM.
Could be since the BOM and CPL is autogenerated and we forgot to select in KiCad “Do not export to BOM”
@vroland I will take a look at it tomorrow

Closed 2024-08-31.

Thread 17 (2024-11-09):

Alternative parts for the Epaper connectors

jonasschnelli, 2024-11-09:
Is there an alternative part for X05A20H34G and XF2M-3315-1A?

martinberlin, 2024-11-09:
Please check https://github.com/vroland/epdiy-hardware/blob/main/part_alternatives.md
For X05A20H34G I don't think there is currently an alternative option.

Closed 2024-12-08.

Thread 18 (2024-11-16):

R24 confusion

jonasschnelli, 2024-11-16:
In the V7 BOM, R24 has the comment `47.5kΩ ` but `C25819` is `47kΩ`.

```
...
"47.5k","R24","Resistor_SMD:R_0603_1608Metric","C25819"
...
```

https://www.lcsc.com/product-detail/Chip-Resistor-Surface-Mount_UNI-ROYAL-Uniroyal-Elec-0603WAF4702T5E_C25819.html

martinberlin, 2024-11-17:
Is 47K but is really irrelevant and won’t make any difference if it was 47.5k
I think we can close this unless you find something deeper and that is worth a correction.

jonasschnelli, 2024-11-17:
I just opened it because the confusion created a feedback question from the PCB manufacturer (delay). Maybe fixing the comment (changing "47.5k" to "47k") would prevent the next person to stumble over this.

I guess changing the .xml file is not the right way? I would expect it is derived from KiCad file?
https://github.com/vroland/epdiy-hardware/blob/504094f94ef042a6004c3bcda421f0379eb24f40/epdiy-v7/epdiy-v7.xml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

Of course I'm also okay with closing it.

martinberlin, 2024-11-17:
It’s an edge case and it’s the first time I hear that a PCB manufacturer ask for this when they have the exact ID number of the part. But if you feel like fixing it please open a PR. You should edit this with KiCad I’m not entirely sure if it’s that exact part and usually this XMLs are generated automatically by IDE I won’t edit that by hand

Closed 2024-11-27.

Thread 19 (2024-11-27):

EPDiy V7 produced through PCBWay won't work

jonasschnelli, 2024-11-27:
I just got two assembled v7 PCBs produced with the "official" Gerbers/BOM/Positioning files through the company PCBWay.
Connecting the PCB to my USB works (green light on, red light pulsing rhythmically). I see the USB device as 0x7523, 0x1a86 with V 2.64.
However, flashing the firmware (dragon example) with `idf.py flash -b 921600` leads to:
```shell
A serial exception error occurred: device reports readiness to read but returned no data (device disconnected or multiple access on port?)
Note: This error originates from pySerial. It is likely not a problem with esptool, but with the hardware connection or drivers.
```

I can successfully flash the firmware on a EPDiyV5 bought from GoodDisplay.

Could it be that some components where not assembled the right way'? Any hints?

Full output:
```Shell
 dragon git:(main) ✗ idf.py flash -b 921600
/Users/jonasschnelli/esp/v5.1-rc2/esp-idf/tools/check_python_dependencies.py:12: DeprecationWarning: pkg_resources is deprecated as an API. See https://setuptools.pypa.io/en/latest/pkg_resources.html
  import pkg_resources
Executing action: flash
Serial port /dev/cu.usbserial-210
Connecting.......
Detecting chip type... ESP32-S3
Running ninja in directory /Users/jonasschnelli/Documents/dev_eink/epdiy/examples/dragon/build
Executing "ninja flash"...
[1/5] cd /Users/jonasschnelli/Documents/dev_eink/epdiy/examples/dragon/build/esp-idf/esptool_py && /Users/jonasschnelli/.espressif/python_env/idf5.1_py3.13_env/bin/python /Users/jonasschnelli/esp/v5.1-rc2/esp-idf/components/partition_table/check_sizes.py --offset 0x8000 partition --type app /Users/jonasschnelli/Documents/dev_eink/epdiy/examples/dragon/build/partition_table/partition-table.bin /Users/jonasschnelli/Documents/dev_eink/epdiy/examples/dragon/build/dragon_example.bin
dragon_example.bin binary size 0xa69d0 bytes. Smallest app partition is 0x177000 bytes. 0xd0630 bytes (56%) free.
[2/5] Performing build step for 'bootloader'
[1/1] cd /Users/jonasschnelli/Documents/dev_eink/epdiy/examples/dragon/build/bootloader/esp-idf/esptool_py && /Users/jonasschnelli/.espressif/python_env/idf5.1_py3.13_env/bin/python /Users/jonasschnelli/esp/v5.1-rc2/esp-idf/components/partition_table/check_sizes.py --offset 0x8000 bootloader 0x0 /Users/jonasschnelli/Documents/dev_eink/epdiy/examples/dragon/build/bootloader/bootloader.bin
Bootloader binary size 0x53b0 bytes. 0x2c50 bytes (35%) free.
[3/5] No install step for 'bootloader'
[4/5] Completed 'bootloader'
[4/5] cd /Users/jonasschnelli/esp/v5.1-rc2/esp-idf/components/esptool_py && /opt/homebrew/Cellar/cmake/3.26.4/bin/cmake -D IDF_PATH=/Users/jonasschnelli/esp/v5.1-rc2/esp-idf -D "SERIAL_TOOL=/Users/jonasschnelli/.espressif/python_env/idf5.1_py3.13_env/bin/python;;/Users/jonasschnelli/esp/v5.1-rc2/esp-idf/components/esptool_py/esptool/esptool.py;--chip;esp32s3" -D "SERIAL_TOOL_ARGS=--before=default_reset;--after=hard_reset;write_flash;@flash_args" -D WORKING_DIRECTORY=/Users/jonasschnelli/Documents/dev_eink/epdiy/examples/dragon/build -P /Users/jonasschnelli/esp/v5.1-rc2/esp-idf/components/esptool_py/run_serial_tool.cmake
esptool.py --chip esp32s3 -p /dev/cu.usbserial-210 -b 921600 --before=default_reset --after=hard_reset write_flash --flash_mode dio --flash_freq 80m --flash_size 2MB 0x0 bootloader/bootloader.bin 0x10000 dragon_example.bin 0x8000 partition_table/partition-table.bin
esptool.py v4.7.0
Serial port /dev/cu.usbserial-210
Connecting.....

A serial exception error occurred: device reports readiness to read but returned no data (device disconnected or multiple access on port?)
Note: This error originates from pySerial. It is likely not a problem with esptool, but with the hardware connection or drivers.
For troubleshooting steps visit: https://docs.espressif.com/projects/esptool/en/latest/troubleshooting.html
CMake Error at run_serial_tool.cmake:66 (message):

  /Users/jonasschnelli/.espressif/python_env/idf5.1_py3.13_env/bin/python;;/Users/jonasschnelli/esp/v5.1-rc2/esp-idf/components/esptool_py/esptool/esptool.py;--chip;esp32s3
  failed.

FAILED: CMakeFiles/flash /Users/jonasschnelli/Documents/dev_eink/epdiy/examples/dragon/build/CMakeFiles/flash
cd /Users/jonasschnelli/esp/v5.1-rc2/esp-idf/components/esptool_py && /opt/homebrew/Cellar/cmake/3.26.4/bin/cmake -D IDF_PATH=/Users/jonasschnelli/esp/v5.1-rc2/esp-idf -D "SERIAL_TOOL=/Users/jonasschnelli/.espressif/python_env/idf5.1_py3.13_env/bin/python;;/Users/jonasschnelli/esp/v5.1-rc2/esp-idf/components/esptool_py/esptool/esptool.py;--chip;esp32s3" -D "SERIAL_TOOL_ARGS=--before=default_reset;--after=hard_reset;write_flash;@flash_args" -D WORKING_DIRECTORY=/Users/jonasschnelli/Documents/dev_eink/epdiy/examples/dragon/build -P /Users/jonasschnelli/esp/v5.1-rc2/esp-idf/components/esptool_py/run_serial_tool.cmake
ninja: build stopped: subcommand failed.
ninja failed with exit code 1, output of the command is in the /Users/jonasschnelli/Documents/dev_eink/epdiy/examples/dragon/build/log/idf_py_stderr_output_34845 and /Users/jonasschnelli/Documents/dev_eink/epdiy/examples/dragon/build/log/idf_py_stdout_output_34845
```

jonasschnelli, 2024-11-27:
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

jonasschnelli, 2024-11-27:
Closing. Sorry for the noise.
Switching the USB cable and reducing to 460800 bauds fixed it.
Works now.

Closed 2024-11-27.

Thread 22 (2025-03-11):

PCBway out of stock X05A20H34G

nicolamurts, 2025-03-11:
Hi community,
I try to buy 5 board on PCBway, but during the check for the assembly the estimation quote rise to 456$ because the X05A20H34G is Out Of Stock.
searching over the internet I find on LCSC the list of the compatible elements
https://www.lcsc.com/products/FFC-FPC-Flat-Flexible-Connector-Assemblies_545.html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,P%3D0.5mm,Surface%20Mount%EF%BC%8CRight%20Angle%22%5D

Is one of this valid?

martinberlin, 2025-03-11:
As long as it’s 0.5 pitch and bottom connect with 34 pins can be replaced.
But it is not that simple @nicolamurts different footprints might have different solder points for structure even though the pins itself might be very similar.
You will have to open this in KiCad and change the footprint before fabrication

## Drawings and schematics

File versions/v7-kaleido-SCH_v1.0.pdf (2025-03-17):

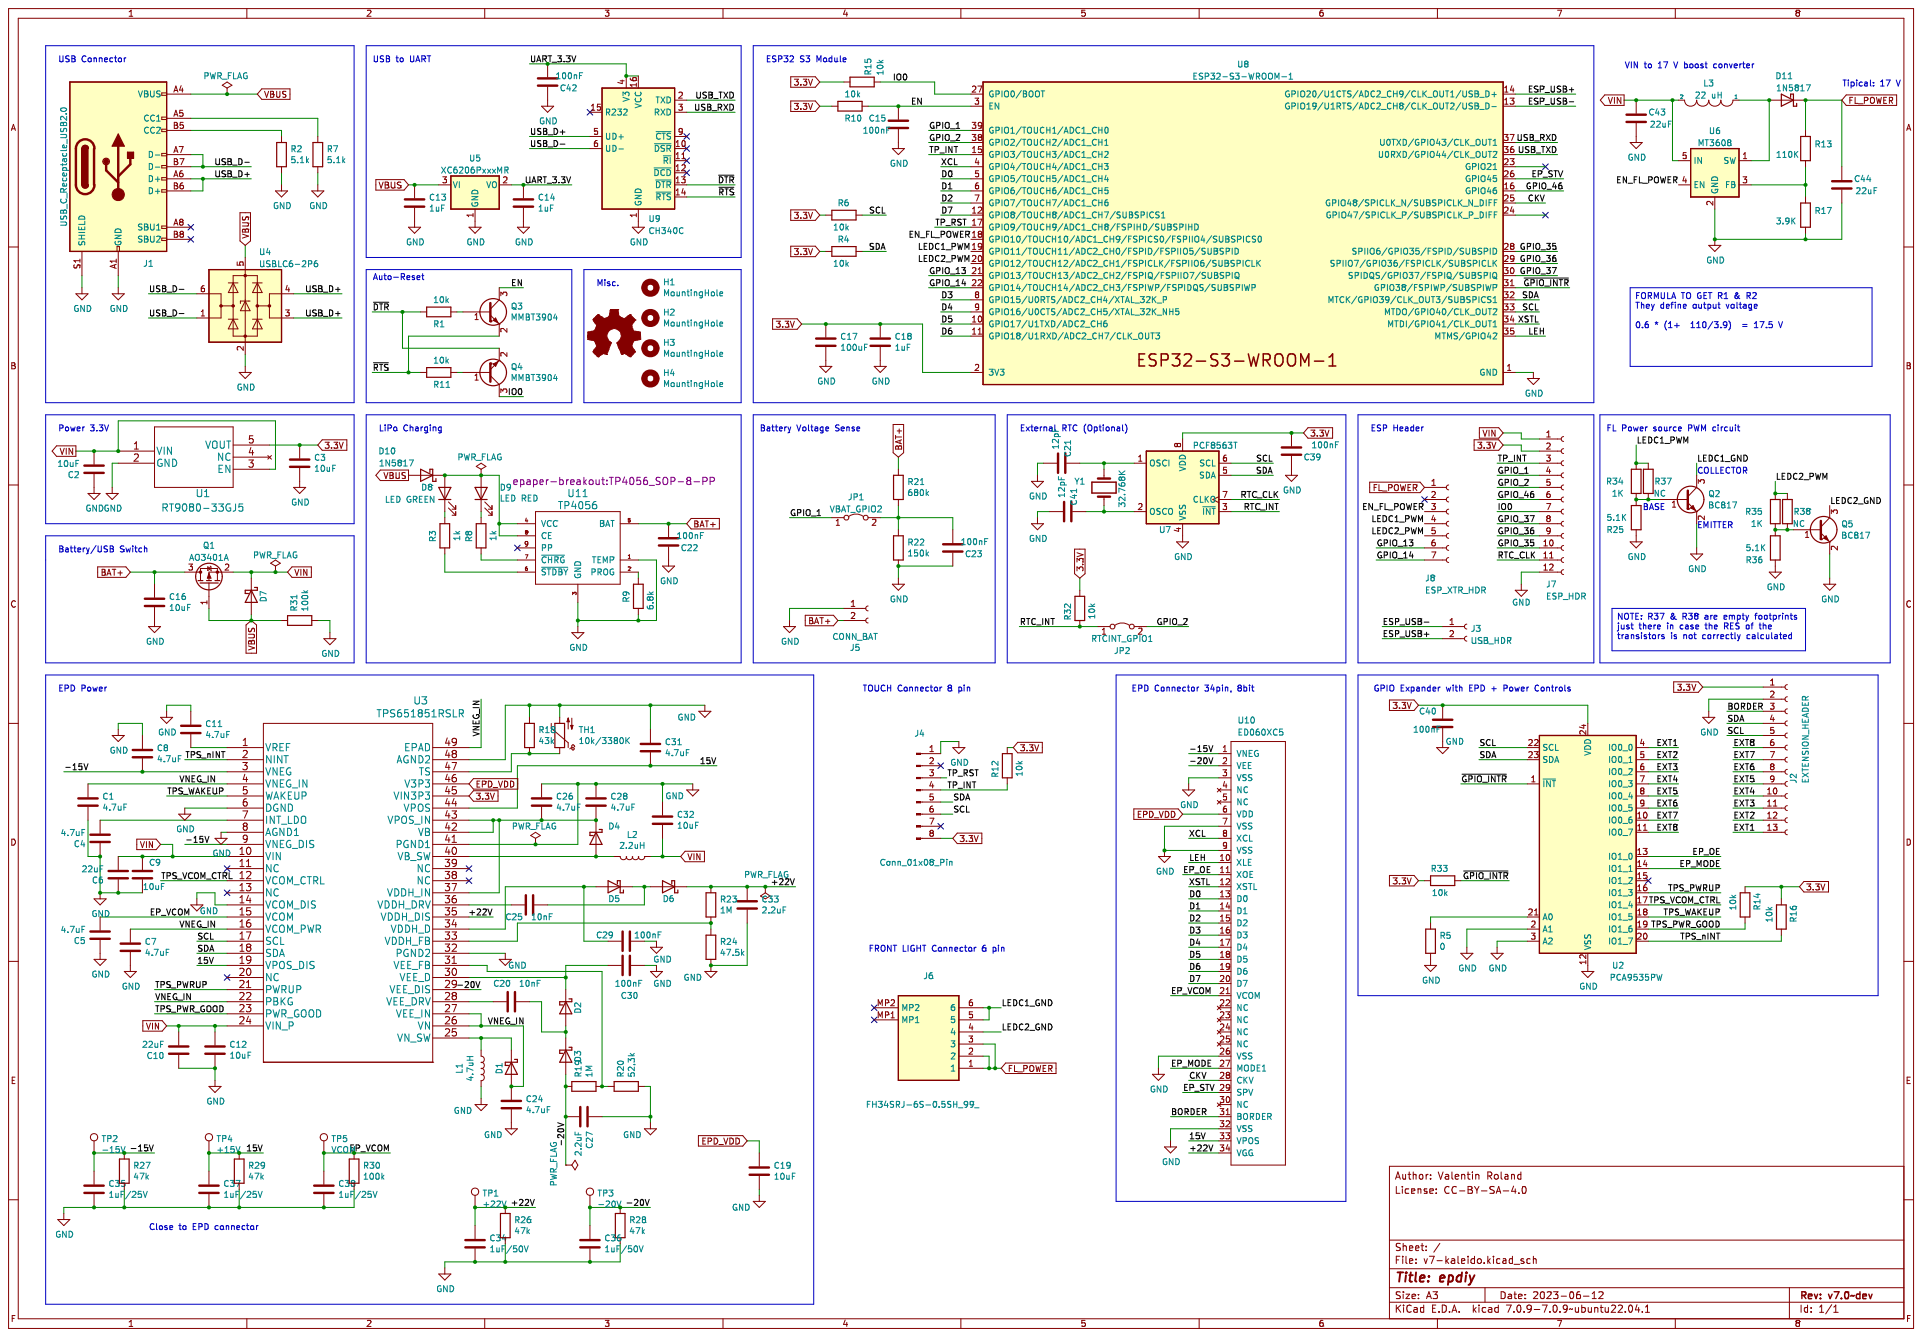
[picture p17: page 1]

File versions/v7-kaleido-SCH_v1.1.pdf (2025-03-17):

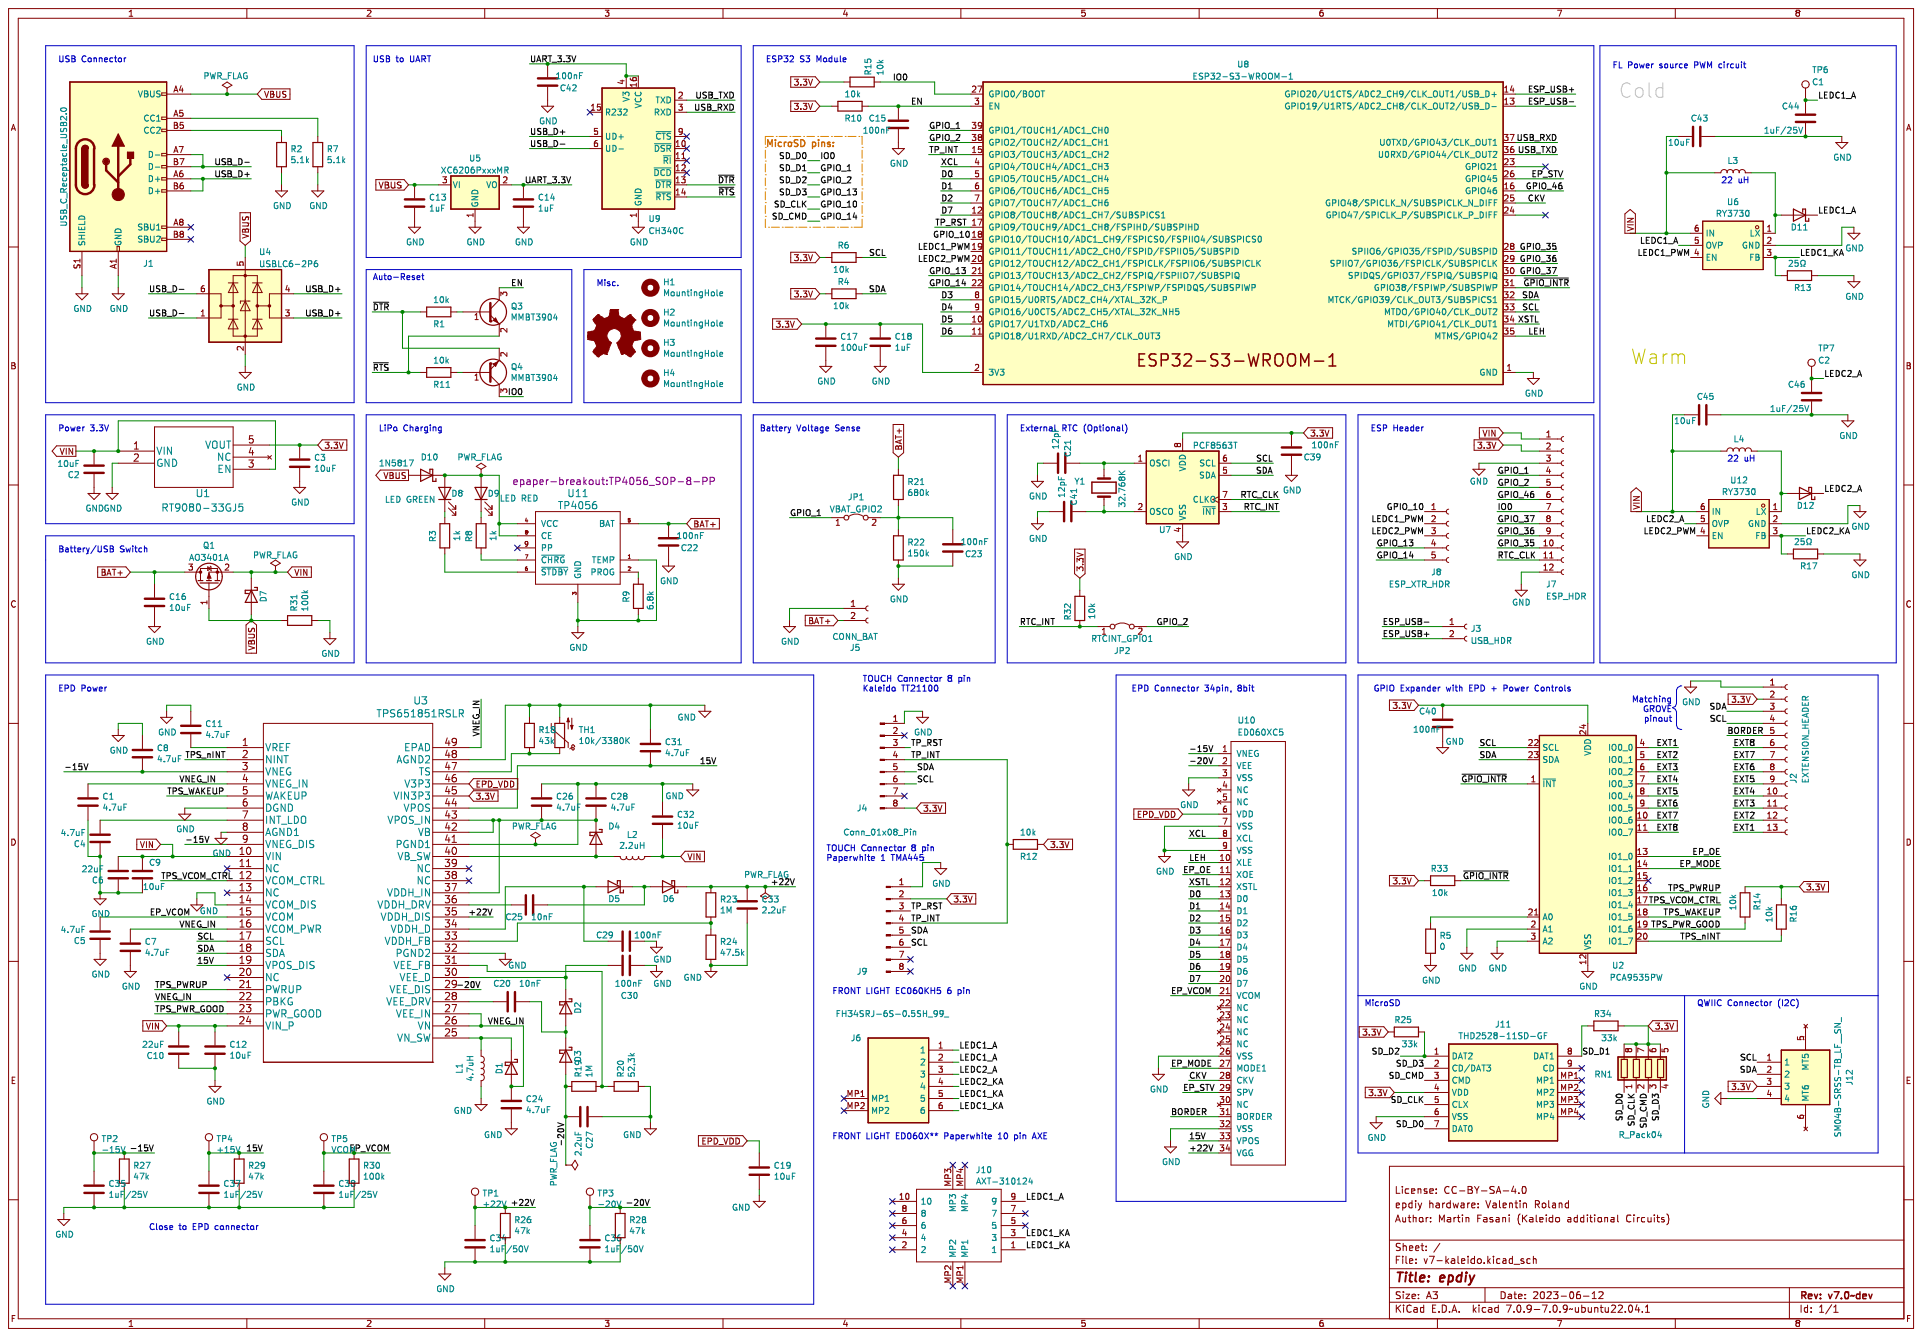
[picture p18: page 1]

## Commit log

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2019-09-06 properly connect micro USB
    [epaper-breakout.sch]
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2019-09-10 reset esp32 manualy
    [epaper-breakout.sch]
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2019-09-11 add footprints for usb, switches, potentiometer
    [epaper-breakout.sch]
2019-09-13 first pcb component clustering
    [epaper-breakout.kicad_pcb, epaper-breakout.sch]
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2019-09-14 fix drc problems
    [epaper-breakout.kicad_pcb]
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2019-09-14 copper pour and ground connections
    [epaper-breakout.kicad_pcb]
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2019-10-04 lower capacity of C15
    [epaper-breakout.sch]
2019-10-04 fix weird fill near u2
    [epaper-breakout.kicad_pcb]
2019-10-04 move C15,C18 closer to ESP power
    [epaper-breakout.kicad_pcb]
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2019-11-01 add lcsc bom for reference
    [bom_LCSC.csv]
2020-03-07 change to wrover module
    [epaper-breakout.sch]
2020-03-11 add second connector, temperature sensor
    [epaper-breakout.sch]
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2020-03-20 move pcb on workspace
    [epaper-breakout.kicad_pcb]
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2020-05-28 updated pdfs and gerbers
    [epaper-breakout-B_Cu.gbr, epaper-breakout-B_Mask.gbr, epaper-breakout-B_Paste.gbr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]
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2020-05-28 Revert "also made new gerbers.zip file"
    This reverts commit 9b41f155298e48c929395310b2c2d23df4f455a4.
2020-05-28 added 5v/3v jumper for LT1945. Also redid a ton of ground vias for better ground plane connection
    [epaper-breakout.kicad_pcb, epaper-breakout.sch]
2020-05-28 update PDF and gerbers for my upgrades
    [epaper-breakout-B_Cu.gbr, epaper-breakout-B_Mask.gbr, epaper-breakout-B_Paste.gbr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]
2020-05-28 add notes on board versions in readme
    [bom_jlcpcb.csv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]
2020-05-28 move vias for larger clearances
    [epaper-breakout.kicad_pcb]
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2020-05-28 unused opamp should be neutralized
    [epaper-breakout.kicad_pcb, epaper-breakout.sch]
2020-05-29 add complete BOM (fix #4)
    [BOM.csv]
2020-05-30 mountingholes are back! (might be slightly misalinged with previous iterations
    [epaper-breakout.kicad_pcb, epaper-breakout.sch]
2020-05-30 added VCOM testpad and silkscreen
    [epaper-breakout.kicad_pcb, epaper-breakout.sch]
2020-05-30 added 3d models, cheated a bit on the potentiometer
    [FH12-33S-0.5SH.stp, S3B-PH-SM4-TB.stp, Tactal Switch - SMD (5mmx 5mmx1.5mm).stp]
2020-05-30 forgot the pcb and cache
    [epaper-breakout.kicad_pcb]
2020-05-30 hide the silkscreen for the mounting holes
    [epaper-breakout.kicad_pcb]
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2020-06-02 adjust relative position of mounting holes
    [epaper-breakout.kicad_pcb]
2020-06-03 Fixed value R14 to 390k as 400k doesnt exist and it will work anyway
    [epaper-breakout.kicad_pcb, epaper-breakout.sch]
2020-06-04 added label with pin numbers for pinheader
    [epaper-breakout.kicad_pcb]
2020-06-25 update gerber files (#14)
    [epaper-breakout-B_Cu.gbr, epaper-breakout-B_Mask.gbr, epaper-breakout-B_Paste.gbr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]
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2020-07-24 add ed133ut2 connector to KiCad lib
    [epaper-breakout.csv, partlist.ods]
2020-07-25 add extension cable pcb
    [extension-cable.kicad_pcb, extension-cable.sch]
2020-09-01 complete designators in BOM
    [BOM.csv]
2020-09-01 add lcsc part number to symbols
    [epaper-breakout.sch]
2020-10-28 add preliminary 3rd hardware revision
    *This is currently untested!*
    A new revision of the hardware, reducing power consumption.
    [epaper-breakout-B_Cu.gbr, epaper-breakout-B_Mask.gbr, epaper-breakout-B_Paste.gbr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]
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2020-10-28 add 3d models for coils
    [epaper-breakout.kicad_pcb]
2020-10-28 add lcsc part numbers
    [epaper-breakout.sch]
2020-10-28 renamve to v4 to differentiate from improved v2
    [epaper-breakout.kicad_pcb]
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2021-01-06 change board license to CC-BY-SA 4.0 (#31)
    [epaper-breakout.sch]
2021-01-25 v5: use ch340g with auto-reset
    [epaper-breakout.sch]
2021-01-25 xc5 connector, power management
    [epaper-breakout.sch]
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2021-01-25 v5: lipo charger circuit
    [epaper-breakout.sch]
2021-01-25 v5 fix pin functions
    [epaper-breakout.sch]
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2021-01-25 remove battery protection, simplify
    [epaper-breakout.kicad_pcb, epaper-breakout.sch]
2021-01-25 add battery voltage sensing, routing
    [epaper-breakout.kicad_pcb, epaper-breakout.sch]
2021-01-25 add decoupling cap to battery voltage sensor
    [epaper-breakout.kicad_pcb, epaper-breakout.sch]
2021-01-25 v5: swap gpio 0 and 19
    [epaper-breakout.kicad_pcb, epaper-breakout.sch]
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2021-01-25 v5: fix mosfet orientation
    [BOM.csv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]
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2021-02-03 Adjust solderpaste after JLCPCB feedback
    [epaper-breakout-B_Cu.gbr, epaper-breakout-B_Mask.gbr, epaper-breakout-B_Paste.gbr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]
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2021-08-25 first schematic based on tps65185
    [epaper-breakout.sch]
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2021-08-25 add additional ground area
    [epaper-breakout.kicad_pcb]
2021-08-25 add tps2113 for power switchover
    [epaper-breakout.kicad_pcb, epaper-breakout.sch]
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2021-08-25 fix testpoint labels
    [epaper-breakout-B_Cu.gbl, epaper-breakout-B_Fab.gbr, epaper-breakout-B_Mask.gbs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]
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2021-08-29 v6: fix battery switchover
    [BOM.csv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]
2021-09-06 Add postion file for manufacture JLC
    [epaper-breakout-top-jlcpcb.csv]
2021-11-28 fix BOM issues
    [BOM.csv, epaper-breakout.sch]
2021-11-28 fix #108
    [epaper-breakout.kicad_pcb]
2022-06-02 Add U3 and U7 to epaper-breakout-top-pos.csv REF https://github.com/vroland/epdiy/issues/153
    [epaper-breakout-top-pos.csv]
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2023-08-31 order file fixes
    [epaper-breakout.kicad_pcb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]
2023-08-31 v7 hardware fixes
    [epaper-breakout-B_Cu.gbl, epaper-breakout-B_Mask.gbs, epaper-breakout-B_Paste.gbp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]
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2023-11-03 rename v7 kicad project to v7
    [epdiy-v7.kicad_pcb, epdiy-v7.kicad_sch]
2023-11-03 migrate extension cable to kicad 7
    [extension-cable.kicad_pcb, extension-cable.kicad_sch, extension-cable.sch]
2023-11-04 fix / roll back mangled v7 pcb
    [epdiy-v7.kicad_pcb]
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2023-11-06 Add helper PCBs: v7 tested + 6" adapters
    [BOM.xlsx, X05A20H34G.step, XKTF-005-SD.stp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]
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2023-11-06 Add silk mentioning that needs a 40 pin Reverse FPC
    [40_pins_PCB_tester.kicad_pcb]
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2023-11-06 move 33 pin to ED133UT2 adapter to adapters folder
    [33_pin_to_ED133UT2.kicad_pcb, 33_pin_to_ED133UT2.kicad_sch, ed133ut2_connector.kicad_pcb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]
2023-11-09 remove wrong ES108FC1 adapter
    [40_pin_to_ES108FC1.kicad_pcb, 40_pin_to_ES108FC1.kicad_sch]
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2023-12-06 Remove the 33 to 34 adapter since it's not working correctly
    Removes the 33 to 34 adapter since it's not working correctly (-15 V is not arriving, not easy to solve, bad layout). Fixes #5
    [9.7_40_to_34_6inch.kicad_pcb, 9.7_40_to_34_6inch.kicad_sch]
2024-04-22 fix v5 C16 / C1 labels (#10)
    [epdiy-v5.kicad_pcb]
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2025-03-17 #1 add Edge-cuts and invert TOUCH pins
    [TP4056-42-ESOP8.step, USB_TYPE-C-31-M-12.step, X05A20H34G_EPD_connector.step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]
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2025-03-17 Update PCB with boost circuit for FL and PWM
    [IND_0S282MT_SNL.step, v7-kaleido.kicad_pcb, v7-kaleido.kicad_sch]
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2025-03-17 Final touches: Add also GROVE pinout on top (SCD40)
    [v7-kaleido.kicad_pcb, v7-kaleido.kicad_sch]
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2025-03-17 #1 sent to prod: 1.1 Kaleido /Kindle board
    [v7-kaleido.kicad_pcb]
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2025-03-17 Rel 1.1 v7 Kaleido + updated raw SCH
    [v7-kaleido-BOM.xlsx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]
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2025-03-17 Fix adapter with correct pinout
    [40_to_WP27D-P050VA3-B_Cu.gbl, 40_to_WP27D-P050VA3-B_Mask.gbs, 40_to_WP27D-P050VA3-B_Paste.gbp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]
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2025-03-17 Updated and NUT SMD corrected (KiCad 8)
    [C2916320_SMTSO2015CTJ.stp, MPU-6500.stp, epdiy-v7-raw.kicad_sch]
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2025-03-17 1.1 corrected IMU to 0x69
    [40_to_EPSON40.kicad_pcb, 40_to_EPSON40.kicad_sch, BOM.csv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]
2025-03-17 Add solderMask in Front side SMD Nuts it was required by JLC
    [epdiy-v7-raw.kicad_pcb]
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2025-03-17 Add single buffer to XCL to decouple when EPD_VDD is low
    [epdiy-v7-raw.kicad_pcb, epdiy-v7-raw.kicad_sch]
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
